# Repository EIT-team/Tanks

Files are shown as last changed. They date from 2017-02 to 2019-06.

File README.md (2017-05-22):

# Head tanks for Electrical Impedance Tomography
---
These head tanks are designed for Electrical Impedance Tomography (EIT) experiments. They are formed of two parts: a head shaped tank, and a skull. This repository contains both an Adult and a neonatal head tank. The geometry is derived from CT/MRI segmentations. The conductivity of the skull is controlled through surface perforations which allow saline to pass through.

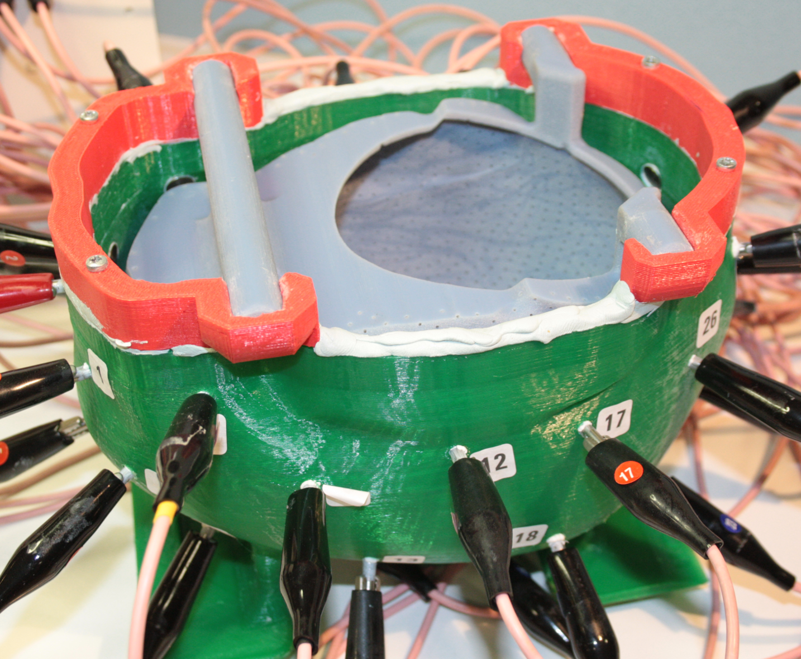
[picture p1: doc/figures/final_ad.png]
Adult tank with KHU connected
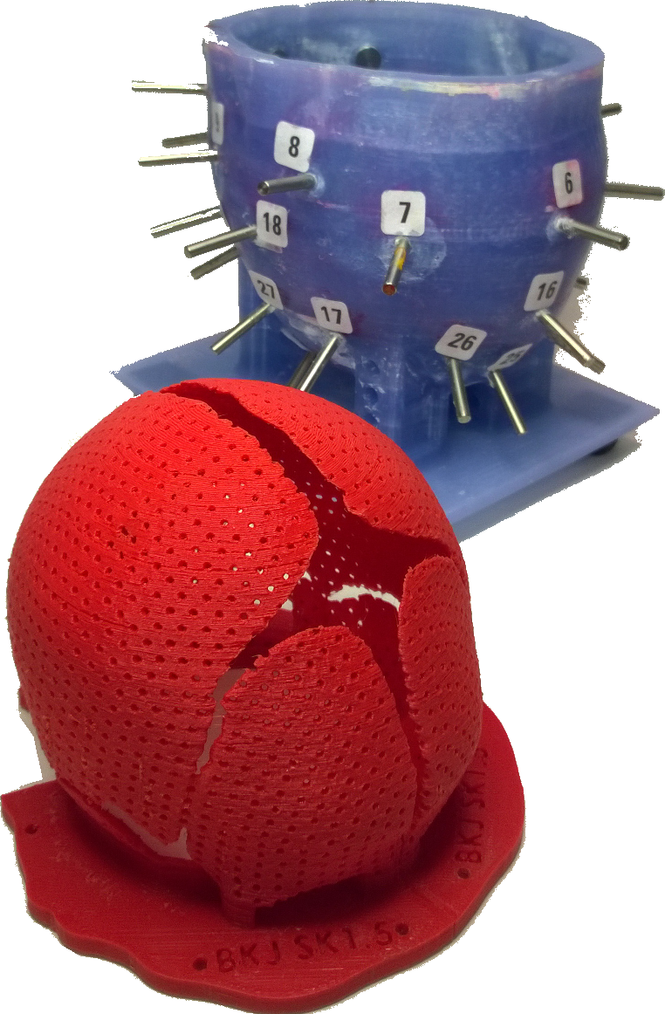
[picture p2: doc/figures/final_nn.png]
Neonatal tank
 

### DESIGN FILES REQUIRE GIT LFS - CONTAINS LOADS OF SOLID MODELS ~2GB DOWNLOAD
Git lfs is *not* required to get printable `.stl` files, only if you want the design files or to edit the electrode positions or the skull conductivities.

### Making tanks
If you are interested in making one of these tanks, please create an __issue__ in the repo or email us, we would love to help you!

To make one of these tanks you will need to:

- Print the tank
- Print the skull
- Remove support material from both models
- Get electrodes from somewhere - either [stainless steel ones](./doc/electrodes) which we had made (We have spares too!), or Ag/AgCl electrodes for the neonatal tank from [biomed electrodes](http://www.biomedelectrodes.com/product/bmd-8/)
- Insert electrodes in tank (somewhat forcefully) and seal with silicon
- Wait to dry
- Insert skull into the tank
- Fill with 0.2% saline
- Collect EIT data
- Win

The `.stl` files are found [here for the neonate tank ](./Neonate/Construction/Printing) and [here for the adult tank ](./Adult/Construction/Printing)

### Using these tanks
If you are using the `.stl` files provided, without changing the conductivities, geometry or electrode positions, then you can use the Meshes and code to generate the `.dgf` files for use with [here](https://github.com/EIT-team/PEITS). The files for the Adult tank are [here](./Adult/Forward_Solver), and [here](./Neonate/Forward_Solver) for the neonatal tank.

### Citing this work
The accompanying journal article for these tanks is found [here](http://iopscience.iop.org/article/10.1088/1361-6579/aa6586)
```
Avery, J. et al., Reproducible 3D printed head tanks for electrical impedance tomography with realistic shape and conductivity distribution. Physiological measurement, 1116.

```

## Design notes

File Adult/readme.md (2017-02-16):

# Adult Head Tank

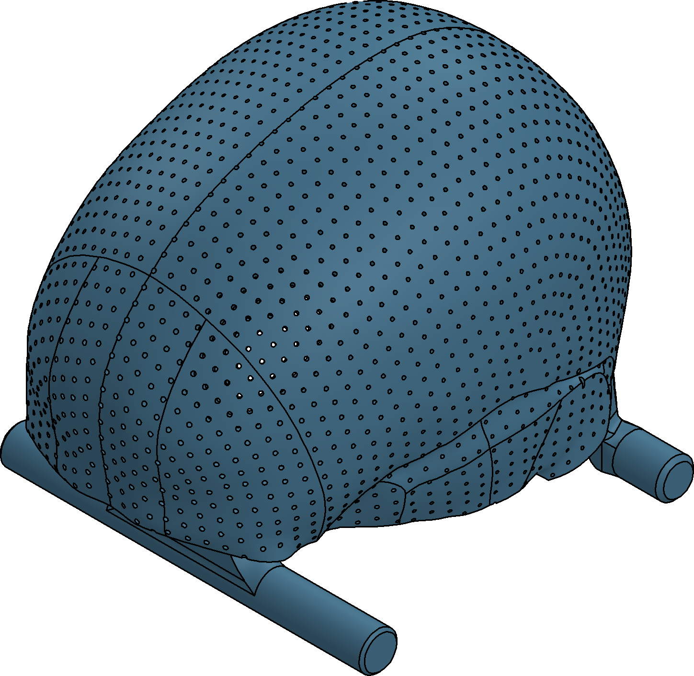
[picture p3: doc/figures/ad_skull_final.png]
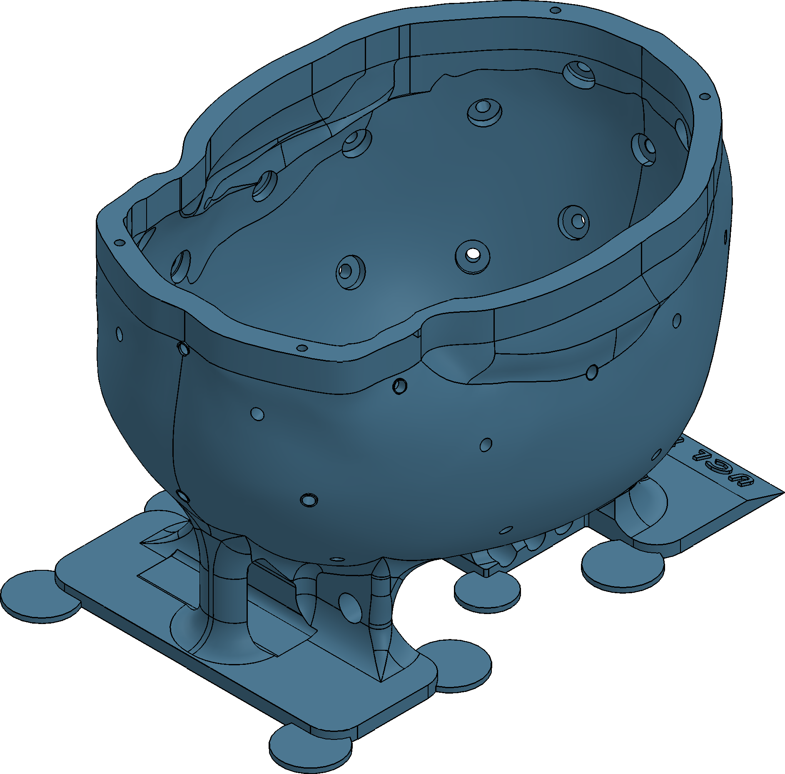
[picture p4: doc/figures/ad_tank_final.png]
Neonatal tank
  

## I just want to print this!

The .stl files are in the `Printing` folder [here](./Construction/Printing)

## Whats in these folders?

- [Construction](./Construction/) has all the design files necessary to make the tank, change the electrode positions/diamaters, as well as changing the conductivity of the skull. This also has the printable `.stl` files
- [Forward_Solver](./Forward_Solver/) has the mesh files and code to generate the things necessary to use this tank in an EIT forward solver, most likely [PEITS](https://github.com/EIT-team/PEITS)
- [Meshing](./Meshing/) has the meshes and Matlab code to convert the solid models to FEMs. Also has the code to generate the Macro to create the holes in the skull.

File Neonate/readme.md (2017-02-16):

# Neonate Head Tank

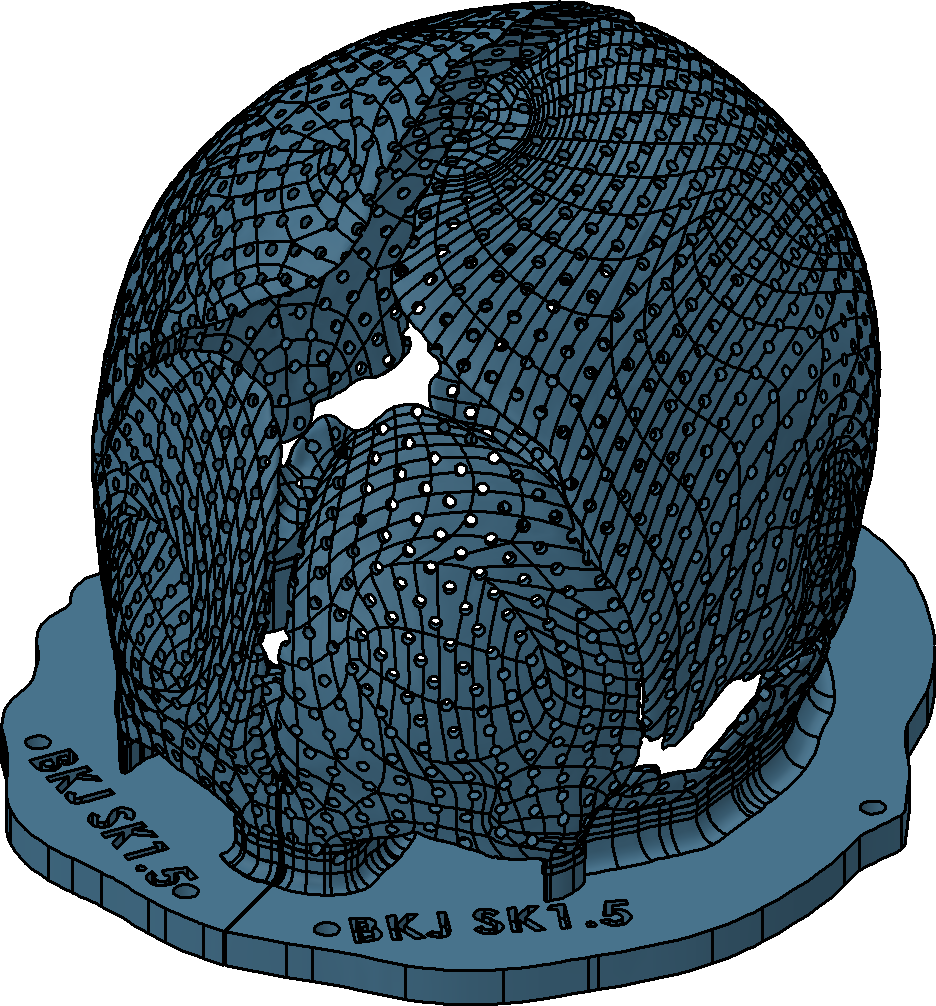
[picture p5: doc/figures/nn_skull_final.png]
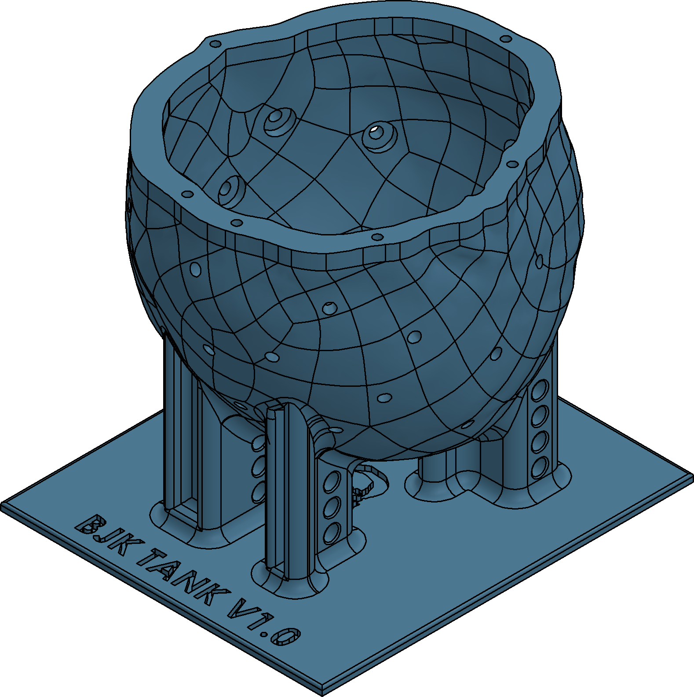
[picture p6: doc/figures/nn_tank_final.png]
Neonatal tank
  

## I just want to print this!

The .stl files are in the `Printing` folder [here](./Construction/Printing)

## Whats in these folders?

- [Construction](./Construction/) has all the design files necessary to make the tank, change the electrode positions/diamaters, as well as changing the conductivity of the skull. This also has the printable `.stl` files
- [Forward_Solver](./Forward_Solver/) has the mesh files and code to generate the things necessary to use this tank in an EIT forward solver, most likely [PEITS](https://github.com/EIT-team/PEITS)
- [Meshing](./Meshing/) has the meshes and Matlab code to convert the solid models to FEMs. Also has the code to generate the Macro to create the holes in the skull.

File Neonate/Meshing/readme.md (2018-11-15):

# Meshing Neonate tank# Meshing neonatal tank

## Generate Cylinders
To make the holes in the skull we need to make loads of cylinders aligned to the surface of the skull. You can load the mesh using `Get_Approx_Mesh_For_Holes`. Using this mesh (or the one included), you can make this macro by running `Create_Cylinder_Macro_For_Holes`. Run the `.FCMacro` file in [FREECAD](https://www.freecadweb.org/)

## Generate Mesh for EIT
Run `SurfToSegmentation` - this creates the .inr file directlty from the stl files of the scalp and skull

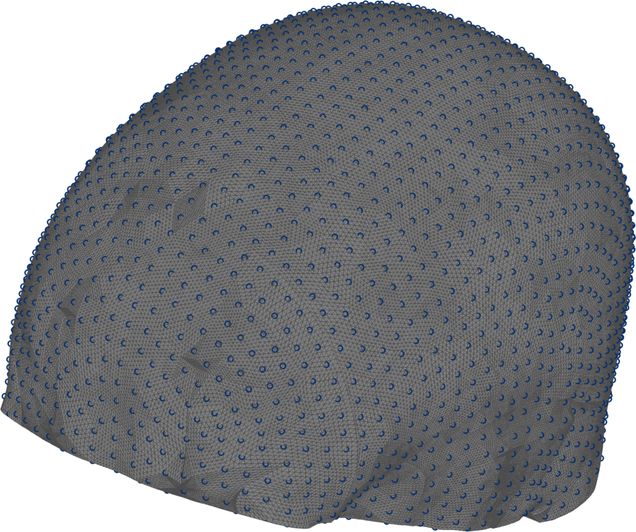
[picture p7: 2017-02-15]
doc/figures/hole_dist.png

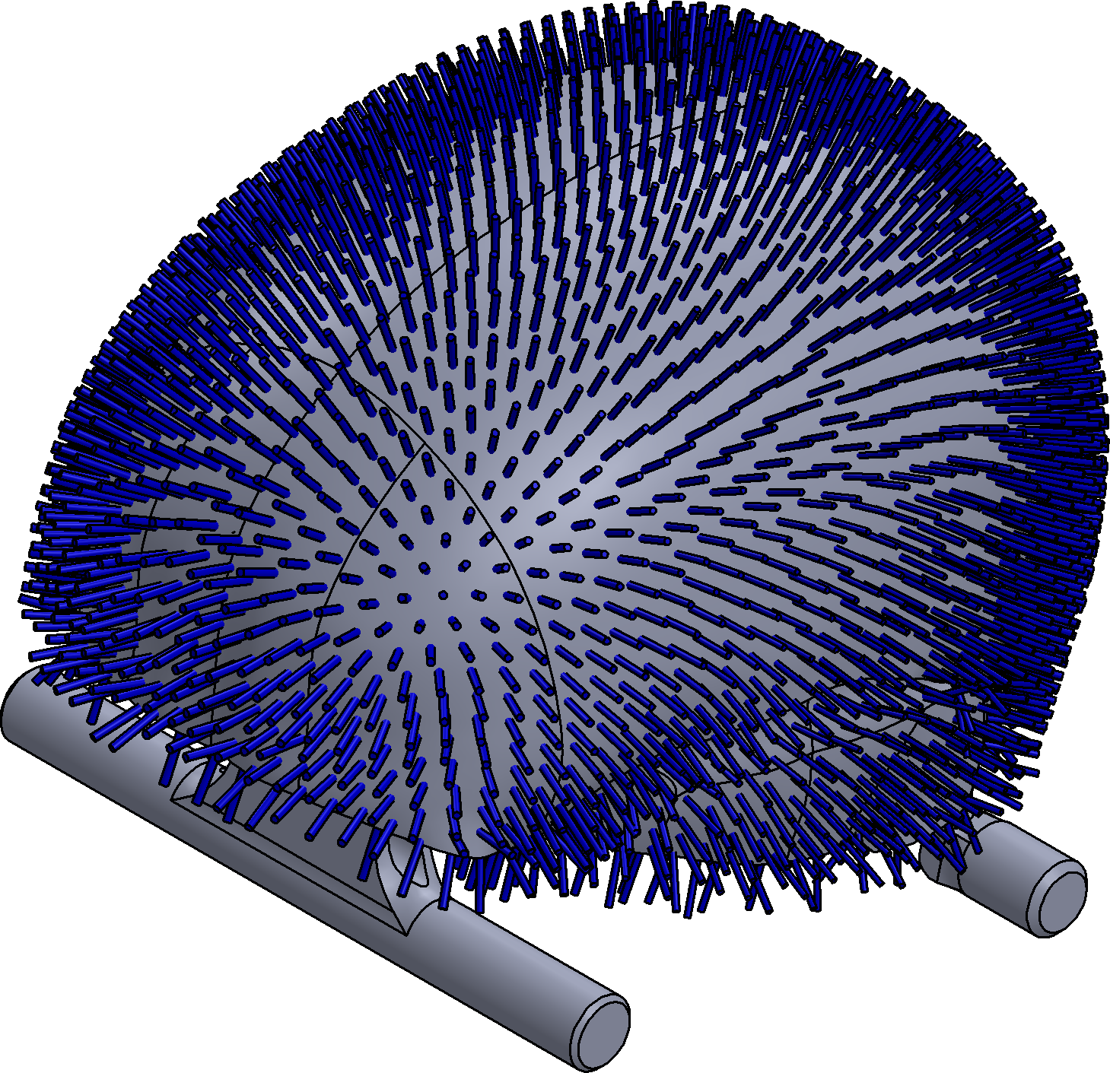
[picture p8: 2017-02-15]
doc/figures/Skull_cyls.png

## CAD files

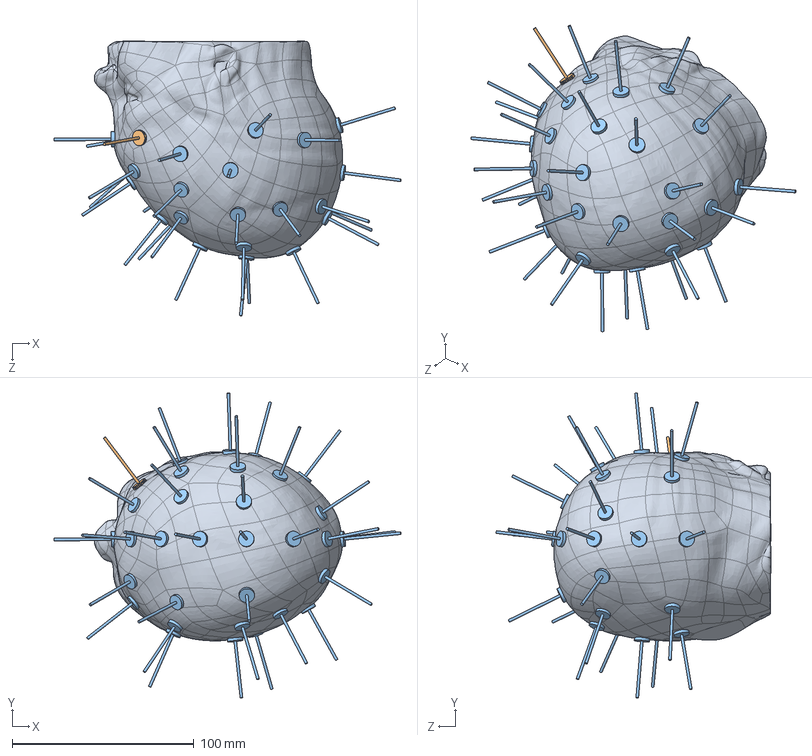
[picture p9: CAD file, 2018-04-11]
Neonate/Construction/Electrode_Positioning/2_Electrode Positioning.SLDASM
190.9 x 167.8 x 151.2 mm
1_Creating_Electrode_Positions x 2
All_AgCl_Positioned

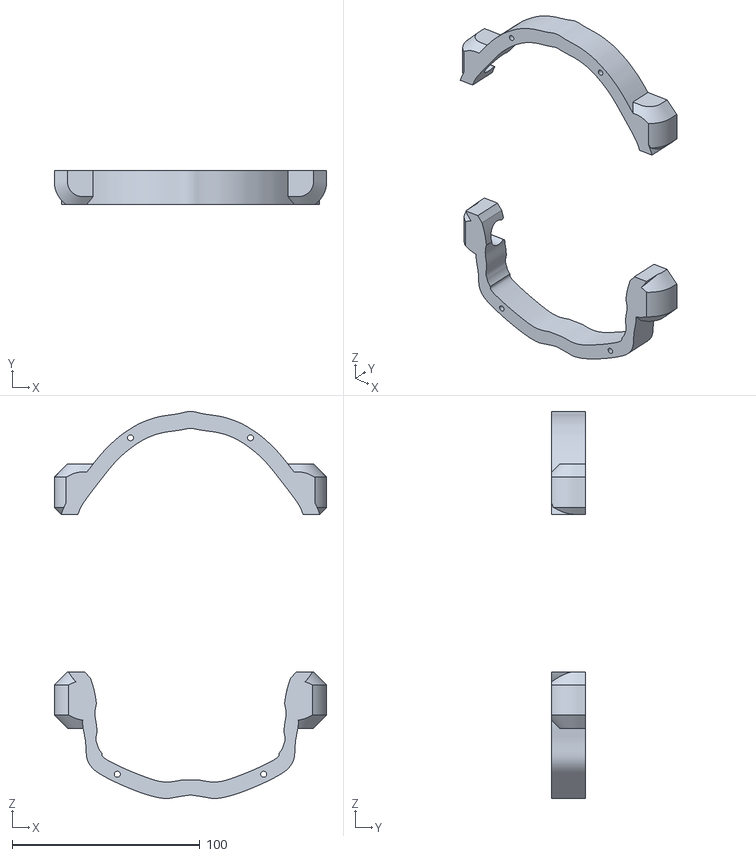
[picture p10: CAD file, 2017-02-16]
Adult/Construction/Printing/3_Skull_holders.STL
145.0 x 18.0 x 205.9

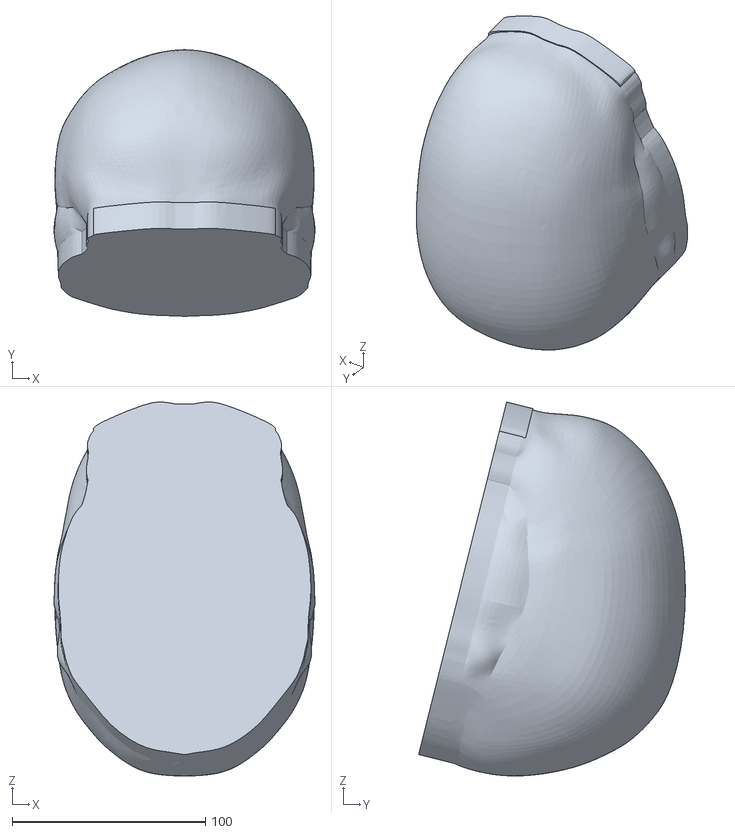
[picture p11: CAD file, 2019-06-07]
Adult/Meshing/AdultTank_Bodies_For_Meshing-Tank.STL
135.1 x 138.1 x 193.7

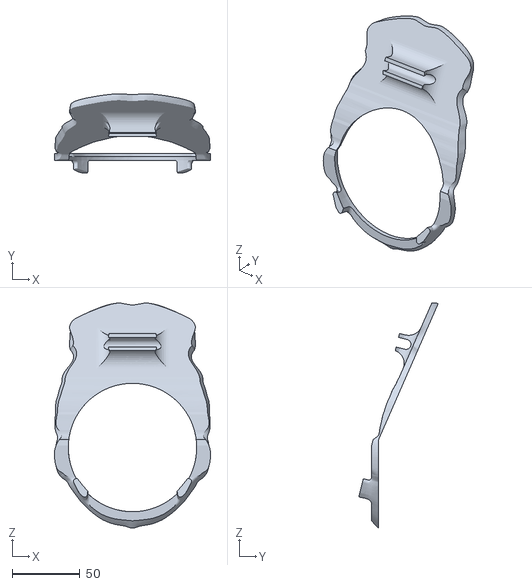
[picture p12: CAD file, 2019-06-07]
Adult/Meshing/AdultTank_Bodies_For_Meshing-SkullSupport.STL
115.5 x 58.8 x 166.4

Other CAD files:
Adult/Construction/Skull/3_Adult_skull_complete.SLDPRT
Neonate/Construction/Skull/4_Neonate_Skull_Complete.STEP
Neonate/Construction/Tank/5_Neonate_Tank_Complete.STEP
Adult/Construction/Electrode_positioning/1_Electrode_Postion_Visualisation.SLDPRT
Adult/Construction/Skull/2_Cylinders_from_FreeCAD_Adult.SLDPRT
Adult/Construction/Tank/1_Adult_tank_final.SLDPRT
doc/electrodes/Electrodes.SLDPRT
Neonate/Construction/Electrode_Positioning/All_AgCl_Positioned.sldprt
Neonate/Construction/Printing/Skull_Aligned_For_Printing.SLDPRT
Neonate/Construction/Skull/1_Neonate_Skull_Split.SLDPRT
Neonate/Construction/Tank/4_Neonate_Tank_Surfaces.SLDPRT
Neonate/Meshing/Bodies_For_Meshing.SLDPRT
Adult/Construction/Skull/1_Skull_with_supports.SLDPRT
Adult/Construction/Tank/2_Final_tank_no_electrodes.sldprt
Adult/Construction/Skull/skull_with_supports.STEP
Adult/Construction/Tank/3_Skull_holders.SLDPRT
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

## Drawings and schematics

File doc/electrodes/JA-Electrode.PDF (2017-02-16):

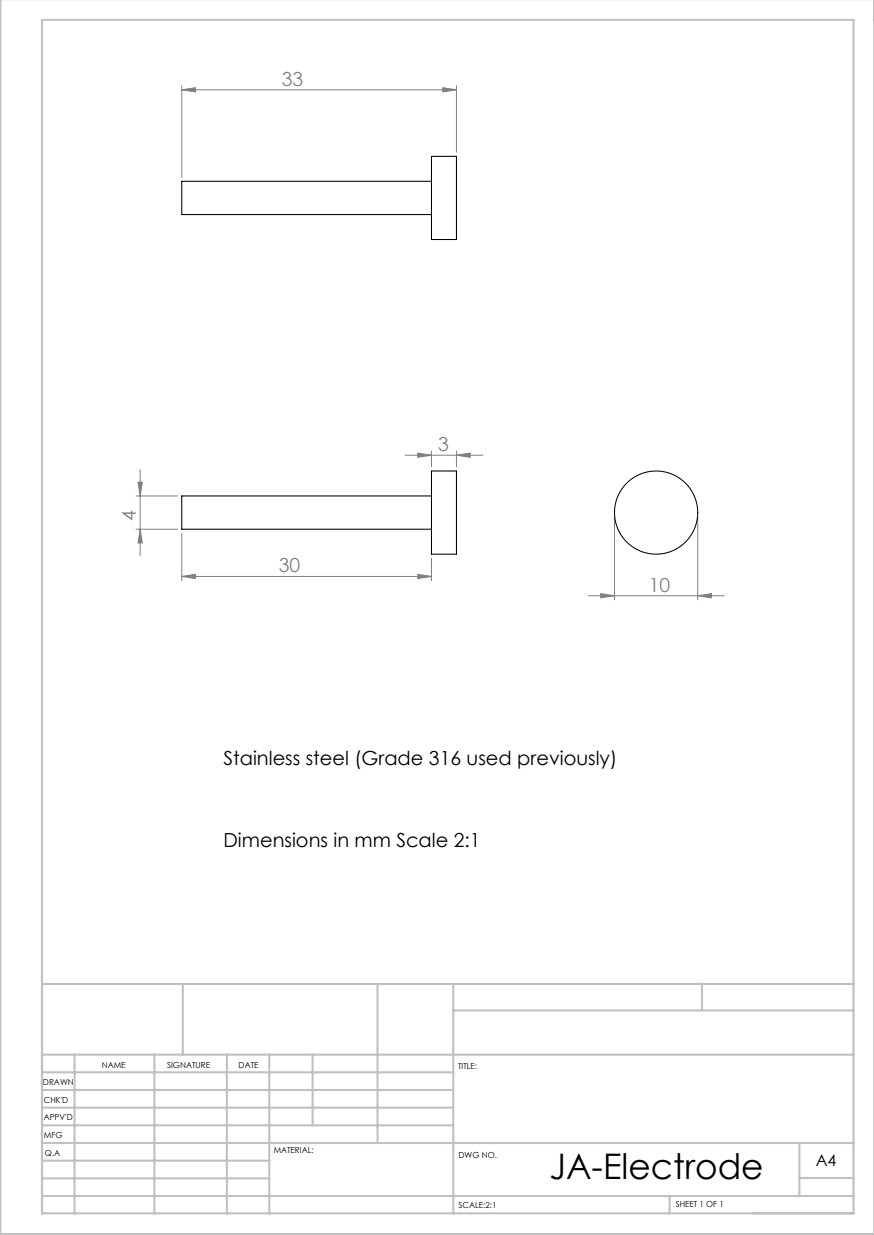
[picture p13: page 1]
SCALE:2:1; SHEET 1 OF 1

Stainless steel (Grade 316 used previously)

Dimensions in mm Scale 2:1

NAME | SIGNATURE | DATE | | | | TITLE:
MATERIAL: | JA-Electrode DWG NO. Q.A | A4

DRAWN
CHK'D
APPV'D
MFG

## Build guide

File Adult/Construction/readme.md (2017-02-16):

# Constructing Adult tank

- [Electrode_Positioning](./Electrode_Positioning/) This had CAD models to position the electrodes based on the EEG 10-20 locations. This model is then subtracted from the tank volume to make the holes to insert the electrodes
- [Printing](./Printing/) __this has the stl files__ Model had to be realigned to make it easier to print flat
- [Skull](./Skull/) has CAD models to create the Skull model from the original conversion from segmentation. Here is where the cylinders generated by the stuff in the [Meshing](../Meshing/) folder is used to create the holes in the skull
- [Tank](./Tank/) CAD models to create the tank from the scalp geometry, originally converted from segmentation. Here is where the electrodes positioned in [Electrode_Positioning](./Electrode_Positioning/) are subtracted to make the holes

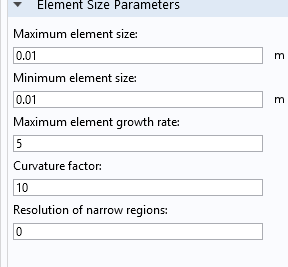
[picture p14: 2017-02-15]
Adult/Meshing/2017_02_15_09_56_15_for_construction.mph_COMSOL_Multiphysics.png

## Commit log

2017-01-24 Added Neonate Tank SLD files
    [0_Electrode_with_clearance .SLDPRT, 2_Stainless_Steel_Electrodes_Positioned.SLDPRT]
2017-01-30 Changed to git LFS, added tank and skull NN parts
    [0_Electrode_with_clearance .SLDPRT, 0_Neonate_Skull.SLDPRT, 1_Neonate_Skull_Split.SLDPRT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]
2017-01-31 added WORKING OMFG generating holes code for NN
    [for_holes.sldprt]
2017-02-01 Added Solid Model to generate COMSOL model
    [Bodies_For_Meshing.SLDPRT]
2017-02-02 Added Creating the Electrode Positions
    [1_Neonate_Scalp.SLDPRT, Scalp_with_electrodes.SLDPRT]
2017-02-02 All electrode positioning now present and correct
    [0_Scalp_with_electrodes_Vis.SLDPRT, 1_Creating_Electrode_Positions.SLDPRT, 1_Neonate_Scalp.STEP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]
2017-02-07 Added Silver Chloride Electrodes. And Numbers on NN tank walls
    [0_Electrode_with_clearance .SLDPRT, 2_Electrode Positioning.SLDASM, 3_Neonate_Tank_Walls.SLDPRT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]
2017-02-08 updated Electrode models
    [2_Electrode Positioning.SLDASM, All_AgCl_Positioned.sldprt, All_Electrodes_Positioned.sldprt]
2017-02-15 Added some figures for the documentation, and code to generate holes in adult skull
    [0_Scalp_with_electrodes_Vis.SLDPRT, 1_Creating_Electrode_Positions.SLDPRT, 1_Neonate_Skull_Split.SLDPRT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]
2017-02-15 added generating cylinders for adult tank
2017-02-15 Added Adult tank stls
    [Adult_tank_final.SLDPRT, Final_tank_no_electrodes.sldprt, Skull_holders.SLDPRT]
2017-02-16 Added stuff to create meshes for forward solver, and cylinder generation macro
    [AdultTank_Bodies_For_Meshing.SLDPRT, AdultTank_Bodies_For_Meshing.x_b]
2017-02-16 updated Tank construction files
    [1_Adult_tank_final.SLDPRT, 2_Final_tank_no_electrodes.sldprt, 3_Skull_holders.SLDPRT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]
2017-02-16 Added files to make skull model
    [1_Skull_with_supports.SLDPRT, 2_Cylinders_from_FreeCAD_Adult.SLDPRT, 3_Adult_skull_complete.SLDPRT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]
2017-02-16 Added generation of electrode positions
    [1_Electrode_Postion_Visualisation.SLDPRT, Electrode positions.xlsx]
2017-02-16 added electrode drawings
    [Electrodes.SLDPRT, JA-Electrode.SLDDRW]
2017-02-16 Added more readmes
    [3_Skull_holders.STL]
2018-04-11 corrected mistake of electrode labeling. Added printable full skull without holes
    [0_Electrode_with_clearance .SLDPRT, 1_Creating_Electrode_Positions.SLDPRT, 1_Neonate_Skull_Split.SLDPRT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]
2018-05-30 Added creating segmentation from surface STLs
    [Bodies_For_Meshing.SLDPRT, Bodies_For_Meshing_Scalp.STL]
2018-06-28 patched skull to prevent holes in lower resolution mesh
2019-06-07 added stl files for skull without holes
    [AdultTank_Bodies_For_Meshing-Skull.STL, AdultTank_Bodies_For_Meshing-SkullSupport.STL, AdultTank_Bodies_For_Meshing-Tank.STL]
